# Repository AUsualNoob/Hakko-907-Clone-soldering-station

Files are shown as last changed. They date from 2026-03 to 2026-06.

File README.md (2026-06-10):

# Hakko 907 Soldering Station

CAD render

## Features

- Arduino Nano based control
- Compatible with Hakko 907 / 907C style handles
- Temperature monitoring
- Adjustable temperature control

---

## PCB

### Schematic

Schematic

Took me a long while. Research and part searching is hard man.

### Tracing

PCB trace

I had to make it 4 layer for my sake, I wouldn't be able to make it 2 layer.

---

## Firmware

There are 2 versions of the firmware.

### Bang-Bang (BB)

Works by having the transistor at either max PWM value or 0 PWM value for increasing and decreasing temperature.

### PID (Proportional-Integral-Derivative)

Adjusts the PWM value depending on how far the current temperature is from the wanted temperature.

It all starts with an error value.

#### Error

The error value is calculated by subtracting the wanted temperature by the current temperature.

```
Error = wantedTemp - currentTemp
```

#### Proportional

That error value is multiplied by a `kP` value. The `kP` value is tweaked to ensure it works properly, it has a default of `2`. The product of the error value and the `kP` value is going to be a part of the PWM value.

```
PWM = kP * Error
```

#### Integral

The integral value has a default of `0`. Usually if the error value gets smaller, the less power goes into the iron, so it usually stays at 10–20 degrees celsius less than the wanted value. This is where the integral comes in — it keeps getting added so you can reach the temperature. It's then multiplied by `kI`, which is also something that should be tweaked, it has a default of `0.5`.

```
integral = integral + error
```

#### Derivative

However the integral value and the error value together usually overshoots, and that's where the derivative comes in. It's then multiplied by `kD`, which has a default value of `0.1` and should also be tweaked.

```
derivative = error - lastError
```

#### Final Output

In the end, it's all put into one float variable, called `pid`, which is then constrained to then be an integer pwm value.

```
pid = (kP * Error) + (kI * integral) + (kD * derivative)
```

```cpp
int pwm = constrain((int)pid, 0, 255);
```

---

## CAD

CAD render

Fusion is hard man.

---

## Finished Product

### Outside









### Inside









---

## BOM

| Qty | Part | Purpose | Cost (USD) | Distributor |
|-----|---|---|---|---|
| 2x | [5mm LEDS](https://www.ram-e-shop.com/shop/led-gg-led-5mm-green-color-5940) | Knowing when it's on or off | 0.019$ | Ram Electronics |
| 1x | [Arduino Nano v3.x](https://www.ram-e-shop.com/shop/kit-arduino-nano-ch340-arduino-nano-328-with-ch340-chip-clone-8338) | Brain of the device | $5.00 | Ram Electronics |
| 1x | [1000µF 50V capacitor](https://www.ram-e-shop.com/shop/c-1000u50v-capacitor-1000uf-50v-6104) | Passive component | $0.10 | Ram Electronics |
| 1x | [100µF 50V capacitor](https://www.ram-e-shop.com/shop/c-100u50v-capacitor-100uf-50v-6073) | Passive component | $0.03 | Ram Electronics |
| 1x | [1N5822](https://www.amazon.eg/-/en/5pcs-1N5822-5822-1N582-Diode/dp/B0DWY2S9S8) | Passive component | $3.00 | Amazon |
| 1x | [1.3" 128x64 I2C OLED display](https://www.ram-e-shop.com/shop/oled-1-3-4pin-oled-1-3-4pin-lcd-display-module-i2c-iic-communicate-7794) | Displaying temperature | $1.75 | Ram Electronics |
| 1x | [1N5240B zener diode](https://www.amazon.eg/-/en/gp/product/B0CWPCPZN2) | Zener diode | $1.50 | Amazon |
| 1x | [RUEF300 polyfuse](https://www.amazon.eg/-/en/gp/product/B0FNLD9RPG) | Protection passive component | $2.00 | Amazon |
| 1x | [GX16-5 connector](https://www.ram-e-shop.com/shop/gx16-5pin-gx16-5-pole-metal-male-female-panel-chassis-connector-7025) | Connector for soldering iron | $1.00 | Ram Electronics |
| 1x | [DC barrel jack](https://www.amazon.eg/-/en/gp/product/B0D4N6JF7F) | Input plug for power | $1.00 | Amazon |
| 1x | [100µH inductor](https://www.amazon.eg/-/en/gp/product/B0FF9X6THF) | Noise reduction | $1.50 | Amazon |
| 1x | [IRF4905 MOSFET](https://www.amazon.eg/-/en/IRF4905-P-Channel-HEXFET-MOSFET-74A/dp/B09H13NQD4) | P-channel MOSFET for reverse polarity protection | $2.00 | Amazon |
| 1x | [IRLZ44N MOSFET](https://www.ram-e-shop.com/shop/irlz44-irlz44n-logic-level-gate-n-channel-mosfet-6633) | N-channel MOSFET for heater control | $1.00 | Ram Electronics |
| 1x | [100k resistor](https://www.ram-e-shop.com/shop/carbon-resistance-1-4w-price-per-4-resistors-9506#attr=314) | Passive component | $0.40 | Ram Electronics |
| 1x | [10k resistor](https://www.ram-e-shop.com/shop/carbon-resistance-1-4w-price-per-4-resistors-9506#attr=314) | Passive component | $0.02 | Ram Electronics |
| 1x | [470Ω resistor](https://www.ram-e-shop.com/shop/carbon-resistance-1-4w-price-per-4-resistors-9506#attr=307) | Passive component | $0.02 | Ram Electronics |
| 1x | [3.3k resistor](https://www.amazon.eg/-/en/Resistor-Through-Electronics-Circuit-Projects/dp/B0GYQ2GYK1) | Passive component | $1.50 | Amazon |
| 1x | [2.7k resistor](https://www.ram-e-shop.com/shop/carbon-resistance-1-4w-price-per-4-resistors-9506#attr=307) | Passive component | $0.02 | Ram Electronics |
| 2x | [2.2k resistor](https://www.amazon.eg/-/en/Resistor-Through-Electronics-Circuit-Projects/dp/B0GYQ2GYK1) | Passive component | $1.00 | Amazon |
| 1x | [Rotary encoder](https://www.ram-e-shop.com/shop/pot-ec11-rotary-5pin-20mm-ec11-rotary-encoder-with-push-button-switch-5pin-20mm-silver-9624) | Controlling temperature | $0.50 | Ram Electronics |
| 1x | [LM2576](https://www.amazon.eg/-/en/gp/product/B0FHHC669J) | Step down converter for the Arduino | $2.00 | Amazon |
| 1x | [LM358 op-amp](https://www.ram-e-shop.com/shop/lm358-copy-lm358p-copy-6130) | OPAMP for amplifying | $0.10 | Ram Electronics |
| 1x | [Soldering Iron Handle](https://www.amazon.eg/-/en/Home-Soldering-Desoldering-Solder-Station/dp/B0GCSY3SBH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) | The handle for the device | 8.20$ | Amazon |
| 1x | [DC Power Adaptor](https://www.amazon.eg/-/en/gp/product/B0FXBHBNHM/ref=ewc_pr_img_7?smid=A2DMKAT7ZKLGQN&psc=1) | Powering the device | 12.41$ | Amazon |
| 5x | PCB | Electrical connections and main body | 7$ | JLCPCB |

**Subtotal: ~$53.1**

**Shipping and Tax: 30$**

**Total: ~83.1$**

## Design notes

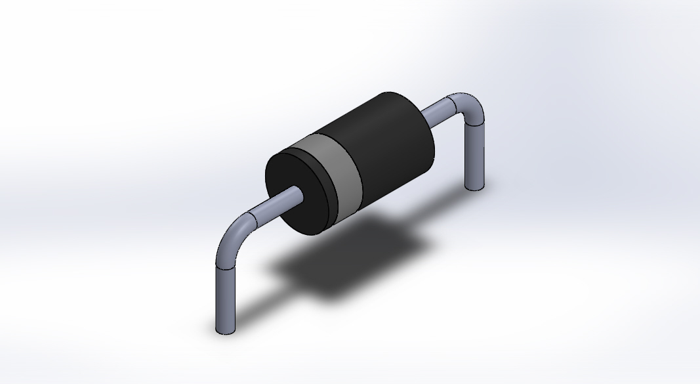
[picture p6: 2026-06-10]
PCB/3D models/Renderings/do-201ad.JPG

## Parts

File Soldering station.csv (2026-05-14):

Name | Purpose | Quantity | Total Cost (USD) | Link | Distributor
Arduino Nano v3.x | Brain of the device | 1 | 5.00 | https://www.ram-e-shop.com/shop/kit-arduino-nano-ch340-arduino-nano-328-with-ch340-chip-clone-8338 | Ram Electronics
1000uF 50V capacitor | Passive component | 1 | 0.10 | https://www.ram-e-shop.com/shop/c-1000u50v-capacitor-1000uf-50v-6104 | Ram Electronics
100uF 50V capacitor | Passive component | 1 | 0.03 | https://www.ram-e-shop.com/shop/c-100u50v-capacitor-100uf-50v-6073 | Ram Electronics
1N5822 | Passive component | 1 | 3.00 | https://www.amazon.eg/-/en/5pcs-1N5822-5822-1N582-Diode/dp/B0DWY2S9S8 | Amazon
1.3 inch 128x64 I2C OLED display | Displaying temperature | 1 | 1.75 | https://www.ram-e-shop.com/shop/oled-1-3-4pin-oled-1-3-4pin-lcd-display-module-i2c-iic-communicate-7794 | Ram Electronics
1N5240B zener diode | Zener diode | 1 | 1.50 | https://www.amazon.eg/-/en/gp/product/B0CWPCPZN2 | Amazon
RUEF300 polyfuse | Protection passive component | 1 | 2.00 | https://www.amazon.eg/-/en/gp/product/B0FNLD9RPG | Amazon
GX16-5 connector | Connector for soldering iron | 1 | 1.00 | https://www.ram-e-shop.com/shop/gx16-5pin-gx16-5-pole-metal-male-female-panel-chassis-connector-7025 | Ram Electronics
DC barrel jack | Input plug for power | 1 | 1.00 | https://www.amazon.eg/-/en/gp/product/B0D4N6JF7F | Amazon
100uH inductor | Noise reduction | 1 | 1.50 | https://www.amazon.eg/-/en/gp/product/B0FF9X6THF | Amazon
IRF4905 MOSFET | P-channel MOSFET for reverse polarity protection | 1 | 2.00 | https://www.amazon.eg/-/en/IRF4905-P-Channel-HEXFET-MOSFET-74A/dp/B09H13NQD4 | Amazon
IRLZ44N MOSFET | N-channel MOSFET for heater control | 1 | 1.00 | https://www.ram-e-shop.com/shop/irlz44-irlz44n-logic-level-gate-n-channel-mosfet-6633 | Ram Electronics
100k resistor | Passive component | 1 | 0.40 | https://www.ram-e-shop.com/shop/carbon-resistance-1-4w-price-per-4-resistors-9506#attr=314 | Ram Electronics
10k resistor | Passive component | 1 | 0.02 | https://www.ram-e-shop.com/shop/carbon-resistance-1-4w-price-per-4-resistors-9506#attr=314 | Ram Electronics
470 ohm resistor | Passive component | 1 | 0.02 | https://www.ram-e-shop.com/shop/carbon-resistance-1-4w-price-per-4-resistors-9506#attr=307 | Ram Electronics
3.3k resistor | Passive component | 1 | 1.50 | https://www.amazon.eg/-/en/Resistor-Through-Electronics-Circuit-Projects/dp/B0GYQ2GYK1 | Amazon
2.7k resistor | Passive component | 1 | 0.02 | https://www.ram-e-shop.com/shop/carbon-resistance-1-4w-price-per-4-resistors-9506#attr=307 | Ram Electronics
2.2k resistor | Passive component | 2 | 1.00 | https://www.amazon.eg/-/en/Resistor-Through-Electronics-Circuit-Projects/dp/B0GYQ2GYK1 | Amazon
Rotary encoder | Controlling temperature | 1 | 0.50 | https://www.ram-e-shop.com/shop/pot-ec11-rotary-5pin-20mm-ec11-rotary-encoder-with-push-button-switch-5pin-20mm-silver-9624 | Ram Electronics
LM2576 | Step down converter for the Arduino | 1 | 2.00 | https://www.amazon.eg/-/en/gp/product/B0FHHC669J | Amazon
LM358 op-amp | OPAMP for amplifying | 1 | 0.10 | https://www.ram-e-shop.com/shop/lm358-copy-lm358p-copy-6130 | Ram Electronics
Soldering Iron Handle | The handle for the device | 1 | 8.20 | https://www.amazon.eg/-/en/Home-Soldering-Desoldering-Solder-Station/dp/B0GCSY3SBH | Amazon
DC Power Adaptor | Powering the device | 1 | 12.41 | https://www.amazon.eg/-/en/gp/product/B0FXBHBNHM | Amazon
PCB | Electrical connections and main body | 5 | 7.00 | JLCPCB | JLCPCB

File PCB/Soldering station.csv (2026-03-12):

Reference | Qty | Value | DNP | Exclude from BOM | Exclude from Board | Footprint | Datasheet
A1 | 1 | Arduino_Nano_v2.x |  |  |  | Module:Arduino_Nano | https://www.arduino.cc/en/uploads/Main/ArduinoNanoManual23.pdf
C1 | 1 | 1000uF_50V |  |  |  | Capacitor_THT:CP_Radial_D8.0mm_P2.50mm
C3 | 1 | 100uF_50V |  |  |  | Capacitor_THT:CP_Radial_D8.0mm_P3.50mm
D1,D2 | 2 | LED |  |  |  | LED_THT:LED_D5.0mm | ~
D3 | 1 | 1N5822 |  |  |  | PCM_Diode_THT_AKL:D_DO-201AD_P12.70mm_Horizontal | https://www.tme.eu/Document/0e3ba29986d8cf49f92da19e697f30fa/1n5820-22.pdf
DS1 | 1 | OLED_128X64_1.3_I2C |  |  |  | OLED_128X64_1.3_I2C:LCD_OLED_128X64_1.3_I2C
DZ1 | 1 | 1N5240B |  |  |  | PCM_Diode_THT_AKL:D_DO-35_SOD27_P7.62mm_Horizontal_Zener | https://www.tme.eu/Document/9906bac3657dc59bd4a6884b643c759b/1N52xxB.pdf
F1 | 1 | Polyfuse |  |  |  | Fuse:Fuse_BelFuse_0ZRE0005FF_L8.3mm_W3.8mm | ~
J2 | 1 | GX16-5 Connecter |  |  |  | Connector:GX16-5 | ~
J3 | 1 | Barrel_Jack_PTH_Slot |  |  |  | PCM_SparkFun-Connector:Barrel_Jack_PTH_Slot | https://www.sparkfun.com/datasheets/Prototyping/Barrel-Connector-PJ-202A.pdf
L1 | 1 | L |  |  |  | Inductor_THT:L_Toroid_Horizontal_D3.2mm_P6.40mm_Diameter3-5mm_Amidon-T12
Q2 | 1 | IRF4905 |  |  |  | PCM_Package_TO_SOT_THT_AKL:TO-220-3_Horizontal_TabDown | https://www.tme.eu/Document/6b5423f4bc207bf599b8e5a57c2f701a/irf4905.pdf
Q3 | 1 | IRLZ44N |  |  |  | PCM_Package_TO_SOT_THT_AKL:TO-220-3_Horizontal_TabDown | https://www.tme.eu/Document/71cf1899624764088671ce6de5d15eb4/irlz44n.pdf
R1 | 1 | 100k |  |  |  | Resistor_THT:R_Axial_DIN0207_L6.3mm_D2.5mm_P10.16mm_Horizontal
R2 | 1 | 10k_0402 |  |  |  | Resistor_THT:R_Axial_DIN0207_L6.3mm_D2.5mm_P10.16mm_Horizontal
R3 | 1 | 470R_0603 |  |  |  | Resistor_THT:R_Axial_DIN0207_L6.3mm_D2.5mm_P10.16mm_Horizontal
R4 | 1 | 3.3k |  |  |  | Resistor_THT:R_Axial_DIN0207_L6.3mm_D2.5mm_P10.16mm_Horizontal
R5 | 1 | 2.7k |  |  |  | Resistor_THT:R_Axial_DIN0207_L6.3mm_D2.5mm_P10.16mm_Horizontal
R6,R7 | 2 | 2.2k |  |  |  | Resistor_THT:R_Axial_DIN0207_L6.3mm_D2.5mm_P10.16mm_Horizontal
SW1 | 1 | RotaryEncoder |  |  |  | Rotary_Encoder:RotaryEncoder_Alps_EC12E_Vertical_H20mm | ~
SW2 | 1 | SW_DIP_x01 |  |  |  | Button_Switch_THT:SW_DIP_SPSTx01_Piano_10.8x4.1mm_W7.62mm_P2.54mm | ~
U1 | 1 | LM2576HVS-5 |  |  |  | PCM_Package_TO_SOT_THT_AKL:TO-220-5_Horizontal_TabDown | http://www.ti.com/lit/ds/symlink/lm2576.pdf
U2 | 1 | LM358 |  |  |  | PCM_4ms_Package_DIP:DIP-8pin_TH

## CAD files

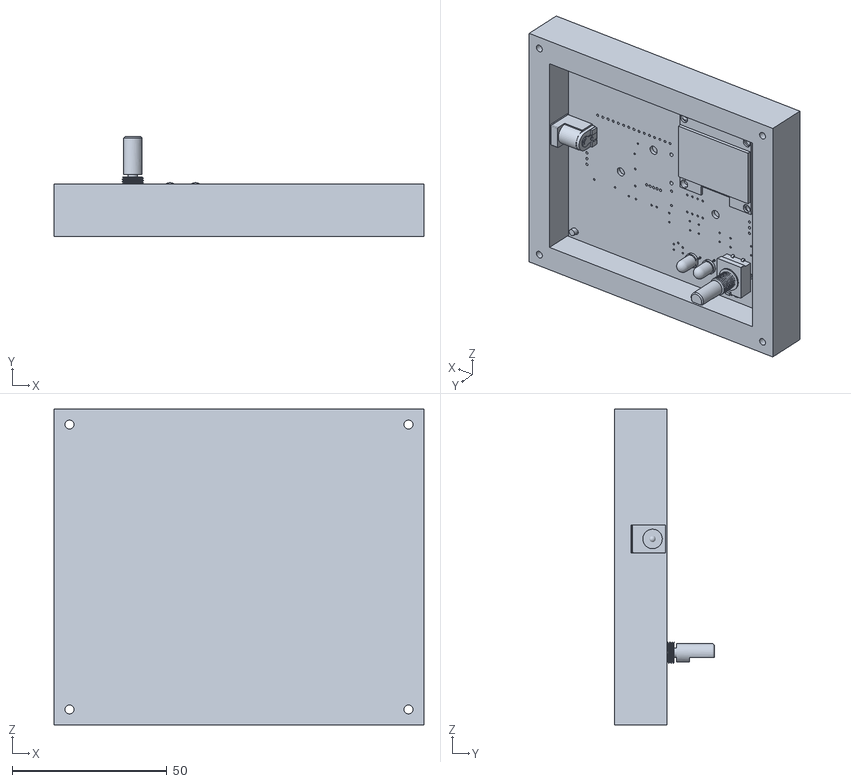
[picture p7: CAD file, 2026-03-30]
CAD/ss.stl
119.5 x 32.3 x 102.0

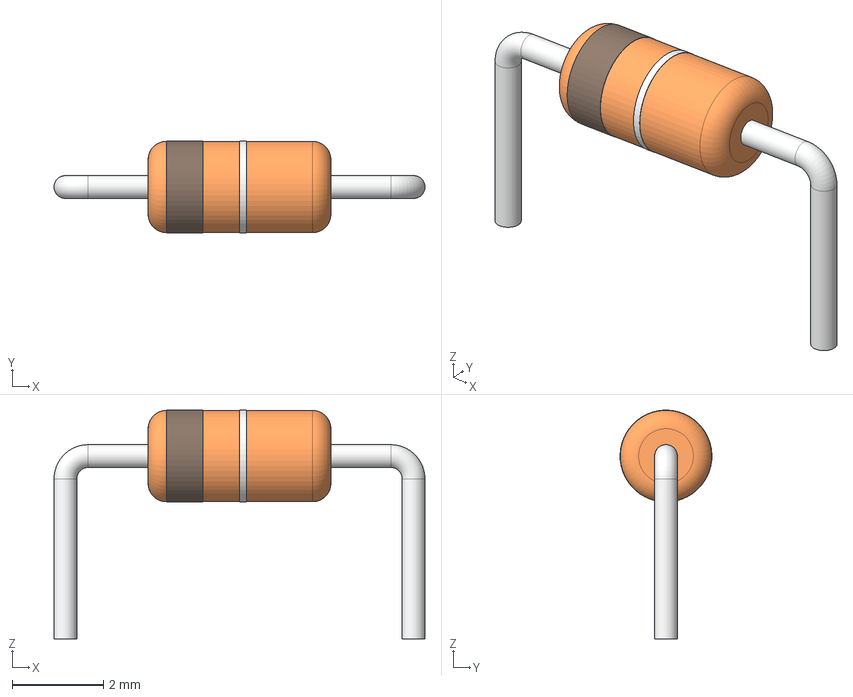
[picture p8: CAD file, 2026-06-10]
PCB/3D models/DO-35.step
8.12 x 2.01 x 5.00 mm
D_DO-35_SOD27_P7.62mm_Horizontal003

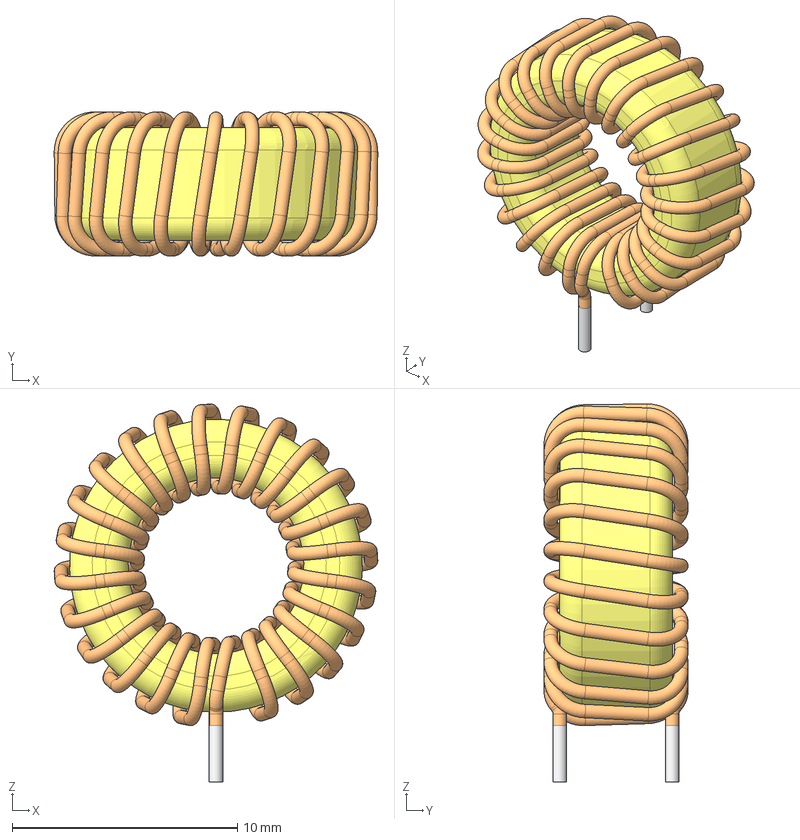
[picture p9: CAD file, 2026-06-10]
PCB/3D models/L_Tor_13x8x5_3a.stp
14.4 x 6.40 x 16.8 mm

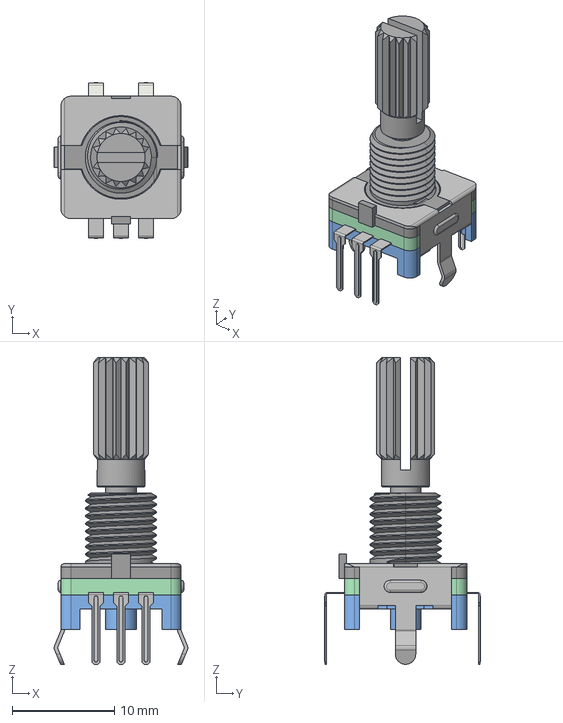
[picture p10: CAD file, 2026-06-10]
PCB/3D models/EC11_Rotary_Encoder_Switched.step
13.1 x 15.3 x 30.1 mm

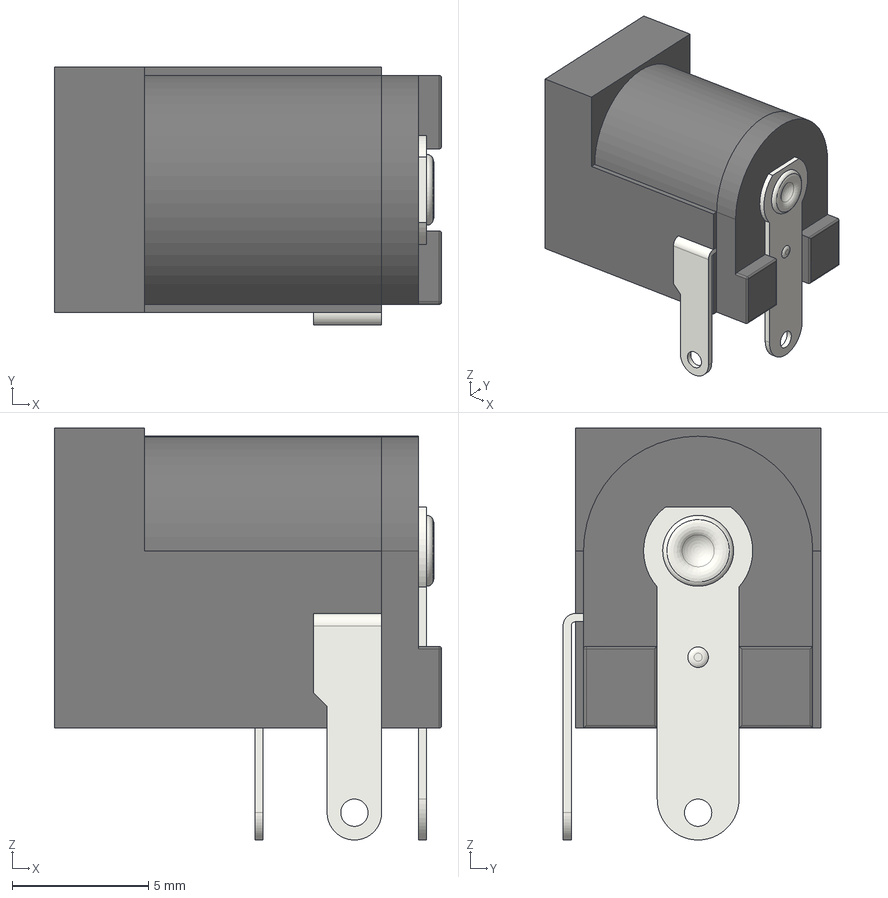
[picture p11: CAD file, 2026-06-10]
PCB/3D models/DC_Power_Jack_PCB_Mounted_2.1mm.step
14.2 x 9.45 x 15.1 mm
Plastic_Body_1of2
Plastic_Body_2of2
PIN_01
PIN_03
PIN_02
Boner

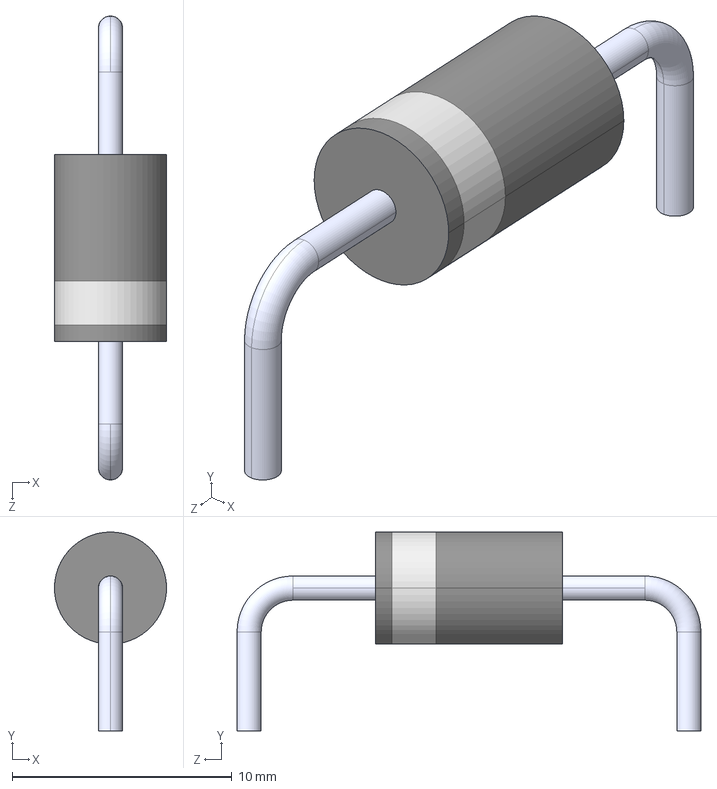
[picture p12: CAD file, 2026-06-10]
PCB/3D models/do-201ad.STEP
5.10 x 9.05 x 21.1 mm
corpo
terminal x 2

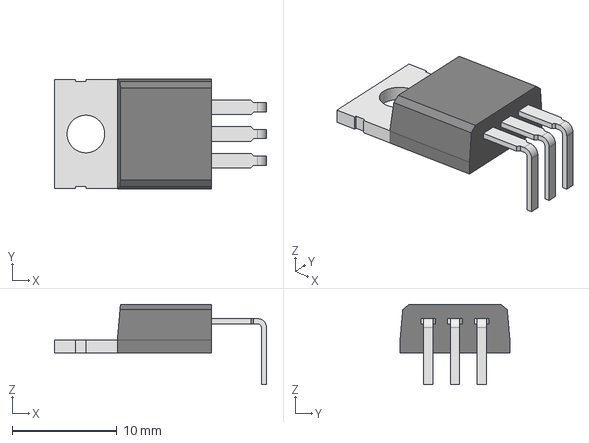
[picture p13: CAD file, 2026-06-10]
PCB/3D models/TO-220_horizontal_line.stp
20.2 x 10.5 x 7.65 mm

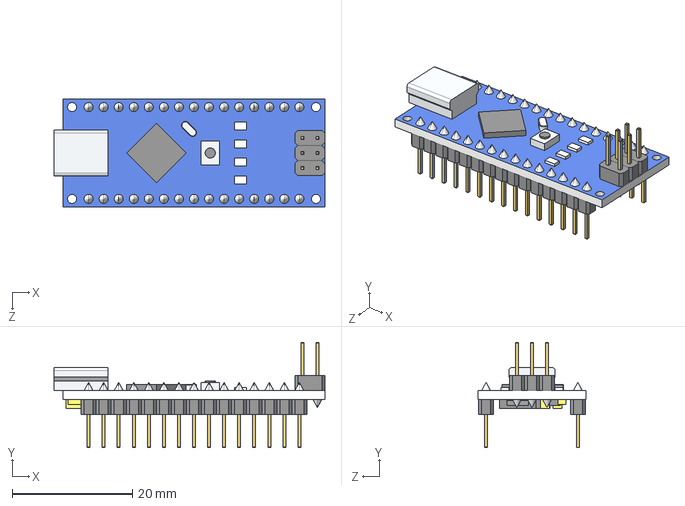
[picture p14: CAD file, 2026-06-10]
PCB/3D models/Arduino_Nano.STEP
45.0 x 17.5 x 18.0 mm

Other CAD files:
PCB/3D models/Arduino_Nano.SLDPRT

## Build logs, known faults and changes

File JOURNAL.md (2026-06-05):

# Journal

---

## 3/16/2026 — Quick reminder for reviewer
*Time spent: 0.1h*

If you don't allow me to buy the soldering iron handle, I can buy it myself if you'd like. You already gave me a soldering iron and I don't wanna waste your money considering you are non-profit.



---

## 3/13/2026 — Big hole on 3D model
*Time spent: 0.1h*

That big hole is supposed to have a panel mount GX16-5 connector / aviation connector. It has a diameter of 18.5mm and I couldn't find a model for it. It isn't mounted onto the PCB but it has cups to put wires in it.



---

## 3/12/2026 — Bigger PCB, mounting holes, case changes
*Time spent: 5h*

I had to do some big changes. First, the PCB — I wanted to add mounting holes since this time I put some tolerance (my dumbass didn't add them in the macropad project) which made the PCB bigger. Thankfully it's less than 100x100mm (still 4 layers, meaning it might cost a bit more), but my PCB will be held in place now.

For the case, I already did some stuff wrong so I had to change it, then I made it bigger because of the mounting holes. Hopefully it's good enough. I think I'll submit after this.




---

## 3/1/2026 — Finished the UI
*Time spent: 6.5h*

It took me so long to make the UI, partially because I didn't know what Lopaka is and making UI was hell, and also because I suck at UI design. I took around 3 hours for the no-Lopaka design (looks bad, I scrapped it) and like 3 or 4 hours to finish the Lopaka design that actually looks good.



---

## 3/1/2026 — Finished the code
*Time spent: 2h*

I finished the code using the PID method. Both methods are stored on my side and if something goes wrong I can just switch until I tweak the code.

Here's a thorough explanation of how the PID method works:

**Error** — calculated by subtracting the wanted temperature by the current temperature.
```
Error = wantedTemp - currentTemp
```

**Proportional** — the error value is multiplied by a `kP` value, tweaked to ensure it works properly. Default: `2`. The product is going to be a part of the PWM value.
```
PWM = kP * Error
```

**Integral** — default of `0`. Usually if the error value gets smaller, the less power goes into the iron, so it usually stays at 10–20 degrees celsius less than the wanted value. This is where the integral comes in — it keeps getting added so you can reach the temperature. Multiplied by `kI`, default: `0.5`.
```
integral = integral + error
```

**Derivative** — the integral and error together usually overshoot, and that's where the derivative comes in. Multiplied by `kD`, default: `0.1`.
```
derivative = error - lastError
```

**Final output** — all put into one float variable called `pid`, then constrained to an integer PWM value.
```
pid = (kP * Error) + (kI * integral) + (kD * derivative)
```
```cpp
int pwm = constrain((int)pid, 0, 255);
```

btw the OLED art will be different, I'm just doing this for it to be quick. Also it's late at night and I'm too lazy to draw.






---

## 2/28/2026 — Finished part of the code
*Time spent: 3h*

I finished the code, however I may redo it considering I found out about the PID method. I'm using the bang-bang method (don't judge me, that's what Claude said when I told him to evaluate my code) and supposedly PID is better, so I'll make 2 versions — one for PID and one for bang-bang.





---

## 2/28/2026 — Finished the case
*Time spent: 0.7h*

Also my first time creating a case without a guide. I'm not the best at 3D design — I'll be really surprised if this works. If this works I'll actually be really happy.



---

## 2/28/2026 — Finished a part of the case
*Time spent: 2h*

I finished quite a big part of the case. All I need left is to make the top part with the holes it needs — I've already done it but I need to double check. Also I removed the switch from the PCB because I used the wrong footprint and it was too big. I want to keep it at less than 100mm so the PCB price will be cheap.





---

## 2/27/2026 — Just finished routing the PCB
*Time spent: 3.5h*

Turns out it had to be a 4-layer PCB. 

For the schematic, I had to use a step down buck converter (the LM2576) so the arduino nano can function properly (and not explode)

For power, I used a barrel jack as an input and a polyfuse and transistor for safety (overcurrent, reverse polarity protection)

A rotary encoder was used for temperatue control, the nano translates it and asks for that specific temperature, forcing the transistor that controls power going into the iron to change how much goes through.

the temperature sensor is connected to an op-amp so reading can be easier.

there's an oled for knowing the temperature.




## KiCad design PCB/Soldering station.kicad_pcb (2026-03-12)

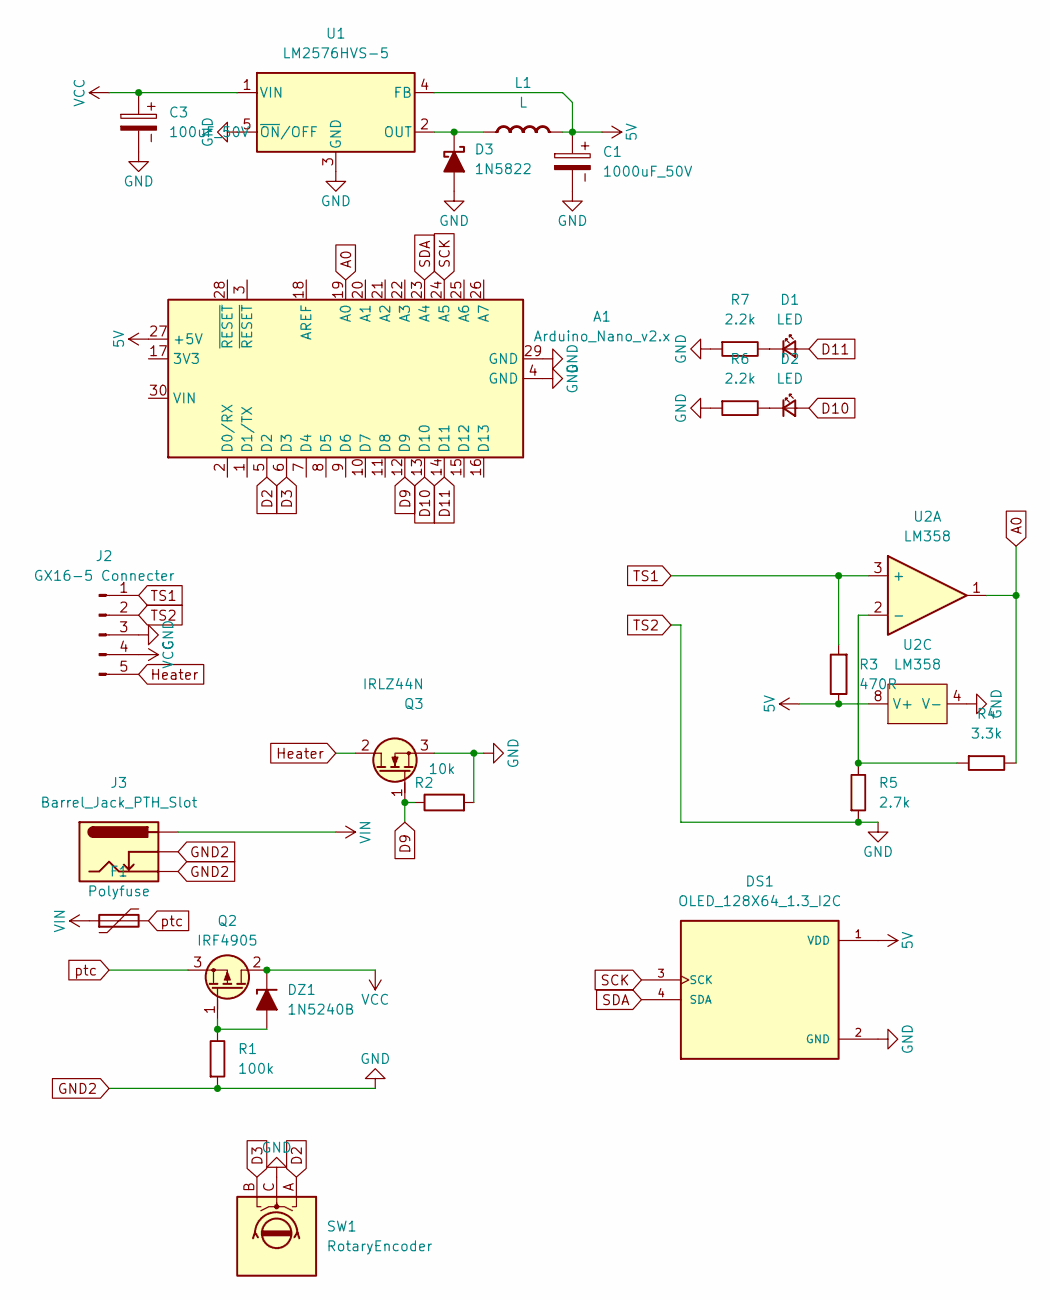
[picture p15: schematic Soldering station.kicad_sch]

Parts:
A1: Arduino_Nano_v2.x; Arduino_Nano
C1: 1000uF_50V; CP_Radial_D8.0mm_P2.50mm
C3: 100uF_50V; CP_Radial_D8.0mm_P3.50mm
D1, D2: LED; LED_D5.0mm
D3: 1N5822; D_DO-201AD_P12.70mm_Horizontal
DS1: OLED_128X64_1.3_I2C; LCD_OLED_128X64_1.3_I2C; PARTREV NA
DZ1: 1N5240B; D_DO-35_SOD27_P7.62mm_Horizontal_Zener
F1: Polyfuse; Fuse_BelFuse_0ZRE0005FF_L8.3mm_W3.8mm
J2: GX16-5 Connecter; GX16-5
J3: Barrel_Jack_PTH_Slot
L1: L; L_Toroid_Horizontal_D3.2mm_P6.40mm_Diameter3-5mm_Amidon-T12; Rating A
Q2: IRF4905; TO-220-3_Horizontal_TabDown
Q3: IRLZ44N; TO-220-3_Horizontal_TabDown
R1: 100k; R_Axial_DIN0207_L6.3mm_D2.5mm_P10.16mm_Horizontal
R2: 10k_0402; R_Axial_DIN0207_L6.3mm_D2.5mm_P10.16mm_Horizontal; Part Number RT0402FRE0710KL
R3: 470R_0603; R_Axial_DIN0207_L6.3mm_D2.5mm_P10.16mm_Horizontal; Part Number RC0603FR-07470RL; JLCPCB ID C23179
R4: 3.3k; R_Axial_DIN0207_L6.3mm_D2.5mm_P10.16mm_Horizontal
R5: 2.7k; R_Axial_DIN0207_L6.3mm_D2.5mm_P10.16mm_Horizontal
R6, R7: 2.2k; R_Axial_DIN0207_L6.3mm_D2.5mm_P10.16mm_Horizontal
SW1: RotaryEncoder; RotaryEncoder_Alps_EC12E_Vertical_H20mm
U1: LM2576HVS-5; TO-220-5_Horizontal_TabDown
U2: LM358; DIP-8pin_TH; JLCPCB ID C7951

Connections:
5V: A1.27 (+5V), C1.1, DS1.1 (VDD), L1.2 (-), R3.1, U1.4 (FB), U2.8 (V+)
A0: A1.19 (A0), R4.2, U2.1
D2: A1.5 (D2), SW1.A
D3: A1.6 (D3), SW1.B
D9: A1.12 (D9), Q3.1 (G), R2.1
D10: A1.13 (D10), D2.2 (A)
D11: A1.14 (D11), D1.2 (A)
GND2: A1.4 (GND), A1.29 (GND), C1.2, C3.2, D3.2 (A), DS1.2 (GND), J2.2, J2.3, J3.GND, J3.GNDBREAK, Q3.3 (S), R1.1, R2.2, R5.1, R6.1, R7.1, SW1.C, U1.3 (GND), U1.5 (~ON/OFF), U2.4 (V-)
Heater: J2.5, Q3.2 (D)
unnamed: D1.1 (K), R7.2
unnamed: D2.1 (K), R6.2
unnamed: D3.1 (K), L1.1 (+), U1.2 (OUT)
unnamed: DZ1.2 (A), Q2.1 (G), R1.2
unnamed: R4.1, R5.2, U2.2 (-)
SCK: A1.24 (A5), DS1.3 (SCK)
SDA: A1.23 (A4), DS1.4 (SDA)
TS1: J2.1, R3.2, U2.3 (+)
VCC: C3.1, DZ1.1 (K), J2.4, Q2.2 (D), U1.1 (VIN)
VIN: F1.1, J3.PWR
ptc: F1.2, Q2.3 (S)

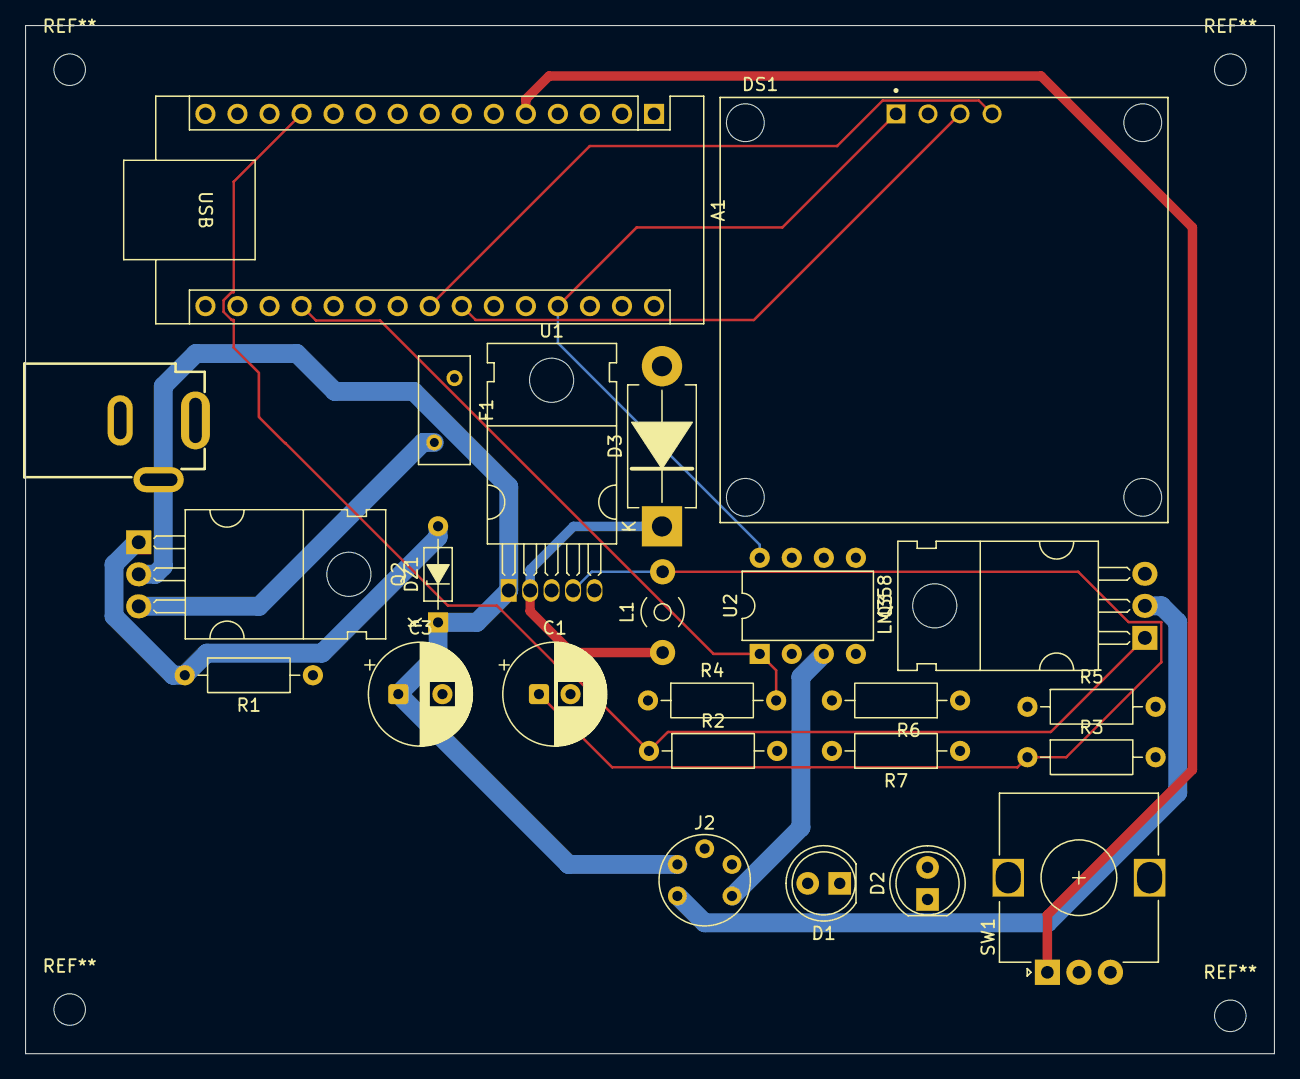
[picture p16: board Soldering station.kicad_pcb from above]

Board: 4 copper layers, 99.0 x 81.5 mm, 24 parts (0 on the bottom side), 20 nets.

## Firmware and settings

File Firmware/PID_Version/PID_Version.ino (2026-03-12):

#include <Wire.h>
#include <U8g2lib.h>

#define tempSensor A0
#define sda A4
#define sck A5
#define LED1 10
#define LED2 11
#define tempControl 9
#define int1 2
#define int2 3

int minTemp = 27;
int maxTemp = 525;
int minADC  = 234;
int maxADC  = 733;

volatile int target = 27;
volatile bool RotaryPinA = false;
volatile bool RotaryPinB = false;
float temp      = 0.0;
float lastError = 0;
float integral  = 0;
float kp = 2.0;
float ki = 0.5;
float kd = 0.1;

unsigned long lastPID = 0;
const int PID_INTERVAL = 100;

static const unsigned char image_Layer_12_bits[] = {0x00,0x06,0x00,0x03,0x80,0x01,0xc1,0x00,0x61,0x00,0x33,0x00,0x1a,0x00,0x0e,0x00};
static const unsigned char image_cross_small_bits[] = {0x00,0x00,0x00,0x00,0x00,0x00,0x00,0x00,0x03,0x03,0x86,0x01,0xcc,0x00,0x78,0x00,0x30,0x00,0x78,0x00,0xcc,0x00,0x86,0x01,0x03,0x03,0x00,0x00,0x00,0x00,0x00,0x00};
static const unsigned char image_Layer_5_bits[] = {0x60,0x00,0x00,0x00,0x00,0x00,0x00,0x00,0x00,0x00,0x00,0x00,0x00,0x00,0x00,0x00,0xfe,0x00,0x00,0x00,0x00,0x00,0x00,0x00,0x00,0x00,0x00,0x00,0x00,0x00,0x00,0x7c,0x3e,0x00,0x00,0x00,0x00,0x00,0x00,0x00,0x00,0x00,0x00,0x00,0x00,0x00,0x00,0x70,0x0e,0x00,0x00,0x00,0x00,0x00,0x00,0x00,0x00,0x00,0x00,0x00,0x00,0x00,0x00,0x60,0x07,0x00,0x00,0x00,0x00,0x00,0x00,0x00,0x00,0x00,0x00,0x00,0x00,0x00,0x00,0xc0,0x03,0x00,0x00,0x00,0x00,0x00,0x00,0x00,0x00,0x00,0x00,0x00,0x00,0x00,0x00,0xc0,0x02,0x00,0x00,0x00,0x00,0x00,0x00,0x00,0x00,0x00,0x00,0x00,0x00,0x00,0x00,0x00,0x00,0x00,0x00,0x00,0x00,0x00,0x00,0x00,0x00,0x00,0x00,0x00,0x00,0x00,0x00,0x00,0x00,0x00,0x00,0x00,0x00,0x00,0x00,0x00,0x00,0x00,0x00,0x00,0x00,0x00,0x00,0x00,0x00,0x00,0x00,0x00,0x00,0x00,0x00,0x00,0x00,0x00,0x00,0x00,0x00,0x00,0x00,0x00,0x00,0x00,0x00,0x00,0x00,0x00,0x00,0x00,0x00,0x00,0x00,0x00,0x00,0x00,0x00,0x00,0x00,0x00,0x00,0x00,0x00,0x00,0x00,0x00,0x00,0x00,0x00,0x00,0x00,0x00,0x00,0x00,0x00,0x00,0x00,0x00,0x00,0x00,0x00,0x00,0x00,0x00,0x00,0x00,0x00,0x00,0x00,0x00,0x00,0x00,0x00,0x00,0x00,0x00,0x00,0x00,0x00,0x00,0x00,0x00,0x00,0x00,0x00,0x00,0x00,0x00,0x00,0x00,0x00,0x00,0x00,0x00,0x00,0x00,0x00,0x00,0x00,0x00,0x00,0x00,0x00,0x00,0x00,0x00,0x00,0x00,0x00,0x00,0x00,0x00,0x00,0x00,0x00,0x00,0x00,0x00,0x00,0x00,0x00,0x00,0x00,0x00,0x00,0x00,0x00,0x00,0x00,0x00,0x00,0x00,0x00,0x00,0x00,0x00,0x00,0x00,0x00,0x00,0x00,0x00,0x00,0x00,0x00,0x00,0x00,0x00,0x00,0x00,0x00,0x00,0x00,0x00,0x00,0x00,0x00,0x00,0x00,0x00,0x00,0x00,0x00,0x00,0x00,0x00,0x00,0x00,0x00,0x00,0x00,0x00,0x00,0x00,0x00,0x00,0x00,0x00,0x00,0x00,0x00,0x00,0x00,0x00,0x00,0x00,0x00,0x00,0x00,0x00,0x00,0x00,0x00,0x00,0x00,0x00,0x00,0x00,0x00,0x00,0x00,0x00,0x00,0x00,0x00,0x00,0x00,0x00,0x00,0x00,0x00,0x00,0x00,0x00,0x00,0x00,0x00,0x00,0x00,0x00,0x00,0x00,0x00,0x00,0x00,0x00,0x00,0x00,0x00,0x00,0x00,0x00,0x00,0x00,0x00,0x00,0x00,0x00,0x00,0x00,0x00,0x00,0x00,0x00,0x00,0x00,0x00,0x00,0x00,0x00,0x00,0x00,0x00,0x00,0x00,0x00,0x00,0x00,0x00,0x00,0x00,0x00,0x00,0x00,0x00,0x00,0x00,0x00,0x00,0x00,0x00,0x00,0x00,0x00,0x00,0x00,0x00,0x00,0x00,0x00,0x00,0x00,0x00,0x00,0x00,0x00,0x00,0x00,0x00,0x00,0x00,0x00,0x00,0x00,0x00,0x00,0x00,0x00,0x00,0x00,0x00,0x00,0x00,0x00,0x00,0x00,0x00,0x00,0x00,0x00,0x00,0x00,0x00,0x00,0x00,0x00,0x00,0x00,0x00,0x00,0x00,0x00,0x00,0x00,0x00,0x00,0x00,0x00,0x00,0x00,0x00,0x00,0x00,0x00,0x00,0x00,0x00,0x00,0x00,0x00,0x00,0x00,0x00,0x00,0x00,0x00,0x00,0x00,0x00,0x00,0x00,0x00,0x00,0x00,0x00,0x00,0x00,0x00,0x00,0x00,0x00,0x00,0x00,0x00,0x00,0x00,0x00,0x00,0x00,0x00,0x00,0x00,0x00,0x00,0x00,0x00,0x00,0x00,0x00,0x00,0x00,0x00,0x00,0x00,0x00,0x00,0x00,0x00,0x00,0x00,0x00,0x00,0x00,0x00,0x00,0x00,0x00,0x00,0x00,0x00,0x00,0x00,0x00,0x00,0x00,0x00,0x00,0x00,0x00,0x00,0x00,0x00,0x00,0x00,0x00,0x00,0x00,0x00,0x00,0x00,0x00,0x00,0x00,0x00,0x00,0x00,0x00,0x00,0x00,0x00,0x00,0x00,0x00,0x00,0x00,0x00,0x00,0x00,0x00,0x00,0x00,0x00,0x00,0x00,0x00,0x00,0x00,0x00,0x00,0x00,0x00,0x00,0x00,0x00,0x00,0x00,0x00,0x00,0x00,0x00,0x00,0x00,0x00,0x00,0x00,0x00,0x00,0x00,0x00,0x00,0x00,0x00,0x00,0x00,0x00,0x00,0x00,0x00,0x00,0x00,0x00,0x00,0x00,0x00,0x00,0x00,0x00,0x00,0x00,0x00,0x00,0x00,0x00,0x00,0x00,0x00,0x00,0x00,0x00,0x00,0x00,0x00,0x00,0x00,0x00,0x00,0x00,0x00,0x00,0x00,0x00,0x00,0x00,0x00,0x00,0x00,0x00,0x00,0x00,0x00,0x00,0x00,0x00,0x00,0x00,0x00,0x00,0x00,0x00,0x00,0x00,0x00,0x00,0x00,0x00,0x00,0x00,0x00,0x00,0x00,0x00,0x00,0x00,0x00,0x00,0x00,0x00,0x00,0x00,0x00,0x00,0x00,0x00,0x00,0x00,0x00,0x00,0x00,0x00,0x00,0x00,0x00,0x00,0x00,0x00,0x00,0x00,0x00,0x00,0x00,0x00,0x00,0x00,0x00,0x00,0x00,0x00,0x00,0x00,0x00,0x00,0x00,0x00,0x00,0x00,0x00,0x00,0x00,0x00,0x00,0x00,0x00,0x00,0x00,0x00,0x00,0x00,0x00,0x00,0x00,0x00,0x00,0x00,0x00,0x00,0x00,0x00,0x00,0x00,0x00,0x00,0x00,0x00,0x00,0x00,0x00,0x00,0x00,0x00,0x00,0x00,0x00,0x02,0x00,0x00,0x00,0x00,0x00,0x00,0x00,0x00,0x00,0x00,0x00,0x00,0x00,0x00,0x40,0x06,0x00,0x00,0x00,0x00,0x00,0x00,0x00,0x00,0x00,0x00,0x00,0x00,0x00,0x00,0x60,0x06,0x00,0x00,0x00,0x00,0x00,0x00,0x00,0x00,0x00,0x00,0x00,0x00,0x00,0x00,0x60,0x06,0x00,0x00,0x00,0x00,0x00,0x00,0x00,0x00,0x00,0x00,0x00,0x00,0x00,0x00,0x70,0x0e,0x00,0x00,0x00,0x00,0x00,0x00,0x00,0x00,0x00,0x00,0x00,0x00,0x00,0x00,0x70,0x3e,0x00,0x00,0x00,0x00,0x00,0x00,0x00,0x00,0x00,0x00,0x00,0x00,0x00,0x00,0x7c,0xfe,0x00,0x00,0x00,0x00,0x00,0x00,0x00,0x00,0x00,0x00,0x00,0x00,0x00,0x00,0x7f,0x20,0x00,0x00,0x00,0x00,0x00,0x00,0x00,0x00,0x00,0x00,0x00,0x00,0x00,0x00,0x00};
static const unsigned char image_Layer_8_bits[] = {0x00,0x00,0x00,0x00,0x00,0x00,0x00,0x00,0x00,0x00,0x00,0x00,0x00,0x00,0xc0,0x00,0x00,0x00,0x00,0x00,0x00,0x00,0x00,0x00,0x00,0x00,0x00,0x00,0x00,0x00,0x00,0x03,0x00,0x00,0x00,0x00,0x00,0x00,0x00,0x00,0x00,0x00,0x00,0x00,0x00,0x00,0x00,0x04,0x00,0x00,0x00,0x00,0x00,0x00,0x00,0x00,0x00,0x00,0x00,0x00,0x00,0x00,0x00,0x08,0x01,0x00,0x00,0x00,0x00,0x00,0x00,0x00,0x00,0x00,0x00,0x00,0x00,0x00,0x00,0x08,0x00,0x00,0x00,0x00,0x00,0x00,0x00,0x00,0x00,0x00,0x00,0x00,0x00,0x00,0x00,0x10,0x00,0x00,0x00,0x00,0x00,0x00,0x00,0x00,0x00,0x00,0x00,0x00,0x00,0x00,0x00,0x00,0x00,0x00,0x00,0x00,0x00,0x00,0x00,0x00,0x00,0x00,0x00,0x00,0x00,0x00,0x00,0x00,0x00,0x00,0x00,0x00,0x00,0x00,0x00,0x00,0x00,0x00,0x00,0x00,0x00,0x00,0x00,0x00,0x00,0x00,0x00,0x00,0x00,0x00,0x00,0x00,0x00,0x00,0x00,0x00,0x00,0x00,0x00,0x00,0x00,0x00,0x00,0x00,0x00,0x00,0x00,0x00,0x00,0x00,0x00,0x00,0x00,0x00,0x00,0x00,0x00,0x00,0x00,0x00,0x00,0x00,0x00,0x00,0x00,0x00,0x00,0x00,0x00,0x00,0x00,0x00,0x00,0x00,0x00,0x00,0x00,0x00,0x00,0x00,0x00,0x00,0x00,0x00,0x00,0x00,0x00,0x00,0x00,0x00,0x00,0x00,0x00,0x00,0x00,0x00,0x00,0x00,0x00,0x00,0x00,0x00,0x00,0x00,0x00,0x00,0x00,0x00,0x00,0x00,0x00,0x00,0x00,0x00,0x00,0x00,0x00,0x00,0x00,0x00,0x00,0x00,0x00,0x00,0x00,0x00,0x00,0x00,0x00,0x00,0x00,0x00,0x00,0x00,0x00,0x00,0x00,0x00,0x00,0x00,0x00,0x00,0x00,0x00,0x00,0x00,0x00,0x00,0x00,0x00,0x00,0x00,0x00,0x00,0x00,0x00,0x00,0x00,0x00,0x00,0x00,0x00,0x00,0x00,0x00,0x00,0x00,0x00,0x00,0x00,0x00,0x00,0x00,0x00,0x00,0x00,0x00,0x00,0x00,0x00,0x00,0x00,0x00,0x00,0x00,0x00,0x00,0x00,0x00,0x00,0x00,0x00,0x00,0x00,0x00,0x00,0x00,0x00,0x00,0x00,0x00,0x00,0x00,0x00,0x00,0x00,0x00,0x00,0x00,0x00,0x00,0x00,0x00,0x00,0x00,0x00,0x00,0x00,0x00,0x00,0x00,0x00,0x00,0x00,0x00,0x00,0x00,0x00,0x00,0x00,0x00,0x00,0x00,0x00,0x00,0x00,0x00,0x00,0x00,0x00,0x00,0x00,0x00,0x00,0x00,0x00,0x00,0x00,0x00,0x00,0x00,0x00,0x00,0x00,0x00,0x00,0x00,0x00,0x00,0x00,0x00,0x00,0x00,0x00,0x00,0x00,0x00,0x00,0x00,0x00,0x00,0x00,0x00,0x00,0x00,0x00,0x00,0x00,0x00,0x00,0x00,0x00,0x00,0x00,0x00,0x00,0x00,0x00,0x00,0x00,0x00,0x00,0x00,0x00,0x00,0x00,0x00,0x00,0x00,0x00,0x00,0x00,0x00,0x00,0x00,0x00,0x00,0x00,0x00,0x00,0x00,0x00,0x00,0x00,0x00,0x00,0x00,0x00,0x00,0x00,0x00,0x00,0x00,0x00,0x00,0x00,0x00,0x00,0x00,0x00,0x00,0x00,0x00,0x00,0x00,0x00,0x00,0x00,0x00,0x00,0x00,0x00,0x00,0x00,0x00,0x00,0x00,0x00,0x00,0x00,0x00,0x00,0x00,0x00,0x00,0x00,0x00,0x00,0x00,0x00,0x00,0x00,0x00,0x00,0x00,0x00,0x00,0x00,0x00,0x00,0x00,0x00,0x00,0x00,0x00,0x00,0x00,0x00,0x00,0x00,0x00,0x00,0x00,0x00,0x00,0x00,0x00,0x00,0x00,0x00,0x00,0x00,0x00,0x00,0x00,0x00,0x00,0x00,0x00,0x00,0x00,0x00,0x00,0x00,0x00,0x00,0x00,0x00,0x00,0x00,0x00,0x00,0x00,0x00,0x00,0x00,0x00,0x00,0x00,0x00,0x00,0x00,0x00,0x00,0x00,0x00,0x00,0x00,0x00,0x00,0x00,0x00,0x00,0x00,0x00,0x00,0x00,0x00,0x00,0x00,0x00,0x00,0x00,0x00,0x00,0x00,0x00,0x00,0x00,0x00,0x00,0x00,0x00,0x00,0x00,0x00,0x00,0x00,0x00,0x00,0x00,0x00,0x00,0x00,0x00,0x00,0x00,0x00,0x00,0x00,0x00,0x00,0x00,0x00,0x00,0x00,0x00,0x00,0x00,0x00,0x00,0x00,0x00,0x00,0x00,0x00,0x00,0x00,0x00,0x00,0x00,0x00,0x00,0x00,0x00,0x00,0x00,0x00,0x00,0x00,0x00,0x00,0x00,0x00,0x00,0x00,0x00,0x00,0x00,0x00,0x00,0x00,0x00,0x00,0x00,0x00,0x00,0x00,0x00,0x00,0x00,0x00,0x00,0x00,0x00,0x00,0x00,0x00,0x00,0x00,0x00,0x00,0x00,0x00,0x00,0x00,0x00,0x00,0x00,0x00,0x00,0x00,0x00,0x00,0x00,0x00,0x00,0x00,0x00,0x00,0x00,0x00,0x00,0x00,0x00,0x00,0x00,0x00,0x00,0x00,0x00,0x00,0x00,0x00,0x00,0x00,0x00,0x00,0x00,0x00,0x00,0x00,0x00,0x00,0x00,0x00,0x00,0x00,0x00,0x00,0x00,0x00,0x00,0x00,0x00,0x00,0x00,0x00,0x00,0x00,0x00,0x00,0x00,0x00,0x00,0x00,0x00,0x00,0x00,0x00,0x00,0x00,0x00,0x00,0x00,0x00,0x00,0x00,0x00,0x00,0x00,0x00,0x00,0x00,0x00,0x00,0x00,0x00,0x00,0x00,0x00,0x00,0x00,0x00,0x00,0x00,0x00,0x00,0x00,0x00,0x00,0x00,0x00,0x00,0x00,0x00,0x00,0x00,0x00,0x00,0x00,0x00,0x00,0x00,0x00,0x00,0x00,0x00,0x00,0x00,0x00,0x00,0x00,0x00,0x00,0x00,0x00,0x00,0x00,0x00,0x00,0x00,0x00,0x00,0x00,0x00,0x00,0x00,0x00,0x00,0x00,0x00,0x00,0x00,0x00,0x00,0x00,0x00,0x00,0x00,0x00,0x00,0x00,0x00,0x00,0x00,0x00,0x00,0x00,0x00,0x00,0x00,0x00,0x00,0x00,0x00,0x00,0x00,0x00,0x00,0x00,0x00,0x00,0x00,0x00,0x00,0x00,0x00,0x00,0x00,0x00,0x00,0x00,0x00,0x00,0x00,0x00,0x00,0x00,0x00,0x00,0x00,0x00,0x00,0x00,0x00,0x00,0x00,0x00,0x00,0x00,0x00,0x00,0x00,0x00,0x00,0x00,0x00,0x00,0x00,0x00,0x00,0x00,0x00,0x00,0x00,0x00,0x00,0x00,0x00,0x00,0x00,0x00,0x00,0x00,0x00,0x00,0x00,0x00,0x00,0x00,0x00,0x00,0x00,0x00,0x00,0x00,0x00,0x00,0x00,0x00,0x00,0x00,0x00,0x00,0x00,0x00,0x00,0x00,0x00,0x00,0x00,0x00,0x00,0x00,0x00,0x00,0x00,0x00,0x00,0x00,0x00,0x00,0x00,0x00,0x00,0x00,0x00,0x00,0x00,0x00,0x00,0x00,0x00,0x00,0x00,0x02,0x00,0x00,0x00,0x00,0x00,0x00,0x00,0x00,0x00,0x00,0x00,0x00,0x00,0x00,0x00};

U8G2_SSD1306_128X64_NONAME_F_HW_I2C u8g2(U8G2_R0, U8X8_PIN_NONE);

void encoder() {
  RotaryPinA = digitalRead(int1);
  RotaryPinB = digitalRead(int2);
  if (RotaryPinB == HIGH) {
    target++;
  } else {
    target--;
  }
  target = constrain(target, minTemp, maxTemp);
  delay(10);
}

void drawScreen(float currentTemp, bool ready) {
  char targetStr[6];
  char tempStr[6];
  itoa(target, targetStr, 10);
  itoa((int)currentTemp, tempStr, 10);
  
  u8g2.setFontMode(1);
  u8g2.setBitmapMode(1);
  u8g2.drawLine(0, 0, 128, 0);
  u8g2.drawLine(0, 0, 0, 63);
  u8g2.drawLine(0, 63, 127, 63);
  u8g2.drawLine(127, 0, 127, 62);
  u8g2.drawXBM(0, 0, 128, 64, image_Layer_5_bits);
  u8g2.drawFrame(0, 7, 128, 49);
  u8g2.drawXBM(2, 1, 125, 59, image_Layer_8_bits);
  u8g2.drawLine(-1, 33, 127, 33);

  u8g2.setFont(u8g2_font_5x8_tr);
  u8g2.drawStr(3, 20, "Current temperature:");
  u8g2.drawStr(2, 30, "Target temperature:");

  u8g2.setFont(u8g2_font_6x10_tr);
  u8g2.drawStr(4, 45, "Start soldering:");

  u8g2.setFont(u8g2_font_6x12_tr);
  u8g2.drawStr(97, 31, targetStr);
  u8g2.drawStr(102, 21, tempStr);

  if (ready) {
    u8g2.drawXBM(101, 38, 11, 8, image_Layer_12_bits);
  } else {
    u8g2.drawXBM(101, 34, 10, 16, image_cross_small_bits);
  }

  u8g2.sendBuffer();
}

void setup() {
  pinMode(tempSensor, INPUT);
  pinMode(int1, INPUT_PULLUP);
  pinMode(int2, INPUT_PULLUP);
  pinMode(tempControl, OUTPUT);
  pinMode(LED1, OUTPUT);
  pinMode(LED2, OUTPUT);
  pinMode(A6, INPUT);
  attachInterrupt(digitalPinToInterrupt(int1), encoder, FALLING);
  u8g2.begin();
}

void loop() {
  unsigned long now = millis();
  if (now - lastPID >= PID_INTERVAL) {
    lastPID = now;

    temp = temp * 0.9 + analogRead(tempSensor) * 0.1;
    float currentTemp = map(temp, minADC, maxADC, minTemp, maxTemp);

    float error = target - currentTemp;
    integral    = integral + error;
    float deriv = error - lastError;
    float pid   = (kp * error) + (ki * integral) + (kd * deriv);
    lastError   = error;
    int pwm     = constrain((int)pid, 0, 255);

    bool ready = (currentTemp >= target && target > minTemp);

    if (target <= minTemp) {
      analogWrite(tempControl, 0);
      digitalWrite(LED1, LOW);
      digitalWrite(LED2, LOW);
      integral = 0;
    } else {
      analogWrite(tempControl, pwm);
      digitalWrite(LED1, pwm > 0 ? HIGH : LOW);
      digitalWrite(LED2, pwm > 0 ? LOW  : HIGH);
    }

    u8g2.clearBuffer();
    drawScreen(currentTemp, ready);
  }
}
